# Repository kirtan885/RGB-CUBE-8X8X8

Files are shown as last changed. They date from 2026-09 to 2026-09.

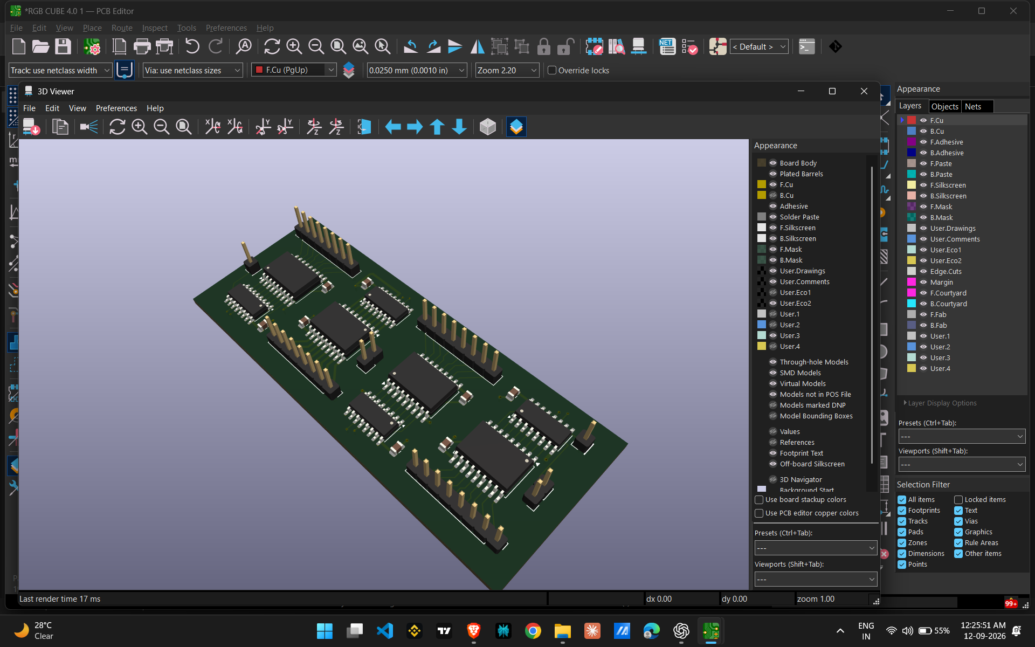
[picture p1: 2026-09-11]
images/Screenshot (306).png

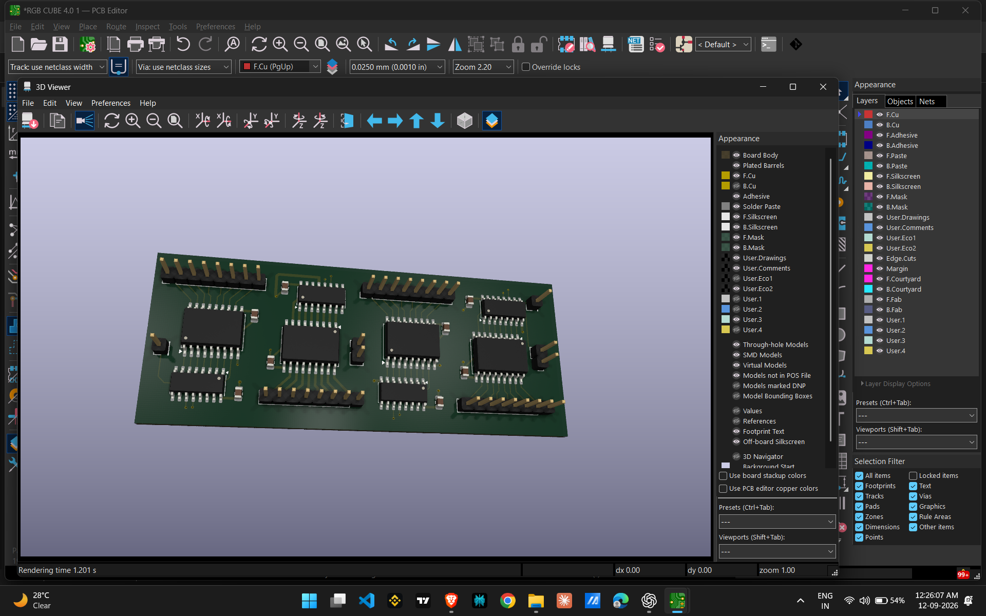
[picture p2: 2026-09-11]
images/pcb-3d.png

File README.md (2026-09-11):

# Arduino 74HC595 8-LED Driver Block Test

A Tinkercad/Arduino Uno validation project for an 8-channel LED driver block using a **74HC595 shift register** and **eight NPN transistor low-side switches**.

The purpose of this block is to validate one repeatable driver section before scaling the design into a larger multiplexed RGB LED cube system.

> **Project status:** Hardware-validation stage / prototype

## Overview

The tested block contains:

- 1 × Arduino Uno
- 1 × 74HC595 8-bit serial-to-parallel shift register
- 8 × NPN transistors (2N2222 / PN2222A or equivalent)
- 8 × LEDs
- 8 × 220 Ω LED current-limiting resistors
- 8 × 1 kΩ transistor base resistors
- 1 × 0.1 µF ceramic decoupling capacitor

The Arduino controls eight LED channels using only three digital control lines:

| Arduino | Signal | 74HC595 |
|---|---|---|
| D11 | Serial DATA | Pin 14, DS/SER |
| D13 | CLOCK | Pin 11, SHCP/SRCLK |
| D10 | LATCH | Pin 12, STCP/RCLK |

The 74HC595 converts the serial data stream into eight parallel outputs. Each output drives an NPN transistor through a 1 kΩ base resistor.

## Circuit architecture

```text
Arduino Uno
   │
   ├── D11 DATA ───────────────► 74HC595 Pin 14 (DS/SER)
   ├── D13 CLOCK ──────────────► 74HC595 Pin 11 (SHCP/SRCLK)
   └── D10 LATCH ──────────────► 74HC595 Pin 12 (STCP/RCLK)
                                  │
                 ┌────────────────┼────────────────┐
                 ▼                ▼                ▼
              Q0..Q7          8 outputs       Pin 9 Q7S
                 │
              1 kΩ each
                 │
                 ▼
            NPN transistor
                 │
        collector ──► LED + 220 Ω ──► +5 V
        emitter   ──────────────────► GND
```

### Low-side switching

For each channel, the intended current path is:

```text
+5V → LED anode → LED cathode → 220 Ω → NPN collector
NPN emitter → GND

74HC595 Q output → 1 kΩ → NPN base
```

When the 74HC595 output is HIGH, the NPN transistor turns on and completes the LED current path to ground.

**Important:** transistor lead order varies between manufacturers and packages. Verify the pin labels of the exact device before wiring a physical prototype.

## 74HC595 power/control wiring

| Arduino / Supply | 74HC595 pin | Function |
|---|---:|---|
| +5 V | 16 | VCC |
| GND | 8 | GND |
| D11 | 14 | DS / SER |
| D13 | 11 | SHCP / SRCLK |
| D10 | 12 | STCP / RCLK |
| GND | 13 | OE, active LOW |
| +5 V | 10 | SRCLR, active LOW |

Two control pins must not be left floating:

```text
74HC595 Pin 13 (OE)   → GND
74HC595 Pin 10 (SRCLR) → +5 V
```

A 0.1 µF ceramic capacitor should be placed close to the IC:

```text
74HC595 Pin 16 (VCC) ──||── 74HC595 Pin 8 (GND)
                       0.1 µF
```

## Output mapping

| Output | Physical pin | Connection |
|---|---:|---|
| Q0 | 15 | 1 kΩ → Transistor 1 base |
| Q1 | 1 | 1 kΩ → Transistor 2 base |
| Q2 | 2 | 1 kΩ → Transistor 3 base |
| Q3 | 3 | 1 kΩ → Transistor 4 base |
| Q4 | 4 | 1 kΩ → Transistor 5 base |
| Q5 | 5 | 1 kΩ → Transistor 6 base |
| Q6 | 6 | 1 kΩ → Transistor 7 base |
| Q7 | 7 | 1 kΩ → Transistor 8 base |
| Q7S / QH' | 9 | Not connected in the single-block test |

For future multi-register designs, Pin 9 (Q7S/QH') of one register connects to Pin 14 (DS/SER) of the next register.

## Bill of materials

| Qty | Component | Value / Type | Purpose |
|---:|---|---|---|
| 1 | Arduino Uno | 5 V board | Controller |
| 1 | 74HC595 | 8-bit shift register | Output expansion |
| 8 | NPN transistor | 2N2222 / PN2222A / equivalent | LED low-side switches |
| 8 | LED | Any color | Visual outputs |
| 8 | Resistor | 220 Ω | LED current limiting |
| 8 | Resistor | 1 kΩ | Transistor base current limiting |
| 1 | Capacitor | 0.1 µF / 104 ceramic | Decoupling |
| 1 | Breadboard | Full/half size | Prototype |
| Several | Jumper wires | — | Interconnects |

## Arduino test firmware

The test sketch runs five patterns:

1. All LEDs ON for approximately 1.5 s
2. All LEDs OFF for approximately 0.8 s
3. Running light from LED 1 to LED 8
4. Binary counter from 0 to 255
5. Bouncing light from one side to the other and back

The sketch uses `shiftOut()` to send eight serial bits and the latch line to update the parallel outputs.

See [`code/74hc595_8_led_test.ino`](code/74hc595_8_led_test.ino).

## Expected result

If all five patterns operate correctly, the following parts of the block have been exercised:

- Arduino-to-74HC595 serial communication
- DATA, CLOCK and LATCH connections
- 74HC595 power and control pins
- Q0–Q7 output mapping
- NPN transistor switching
- LED polarity
- LED current-limiting resistors
- transistor base resistors
- latch timing

## Troubleshooting

| Symptom | Likely cause | Check |
|---|---|---|
| No LEDs light | 74HC595 has no power | Pin 16 = +5 V, Pin 8 = GND |
| All LEDs remain off | OE floating/HIGH | Pin 13 → GND |
| LEDs behave unpredictably | SRCLR floating | Pin 10 → +5 V |
| Random/unstable behavior | Missing decoupling | Add 0.1 µF close to the IC |
| Only some LEDs work | Q-pin mapping error | Q0 = pin 15; Q1–Q7 = pins 1–7 |
| LED stays on | Transistor/LED wiring issue | Check base, collector, emitter and polarity |
| LED does not light | LED reversed | Anode toward +5 V; cathode toward resistor/transistor |
| Sequence is wrong | Physical LED order differs | Match LED order to Q0–Q7 |

## Scaling toward the LED cube

The validated block is intended as the foundation for a larger LED-cube driver.

```text
1 × 74HC595  → 8 output channels
2 × 74HC595  → 16 output channels
8 × 74HC595  → 64 output channels
24 × 74HC595 → 192 output channels
```

For chained registers:

```text
Arduino D11
   │
   ▼
74HC595 #1 DS
   │
   └── Q7S ──► 74HC595 #2 DS
                  │
                  └── Q7S ──► 74HC595 #3 DS
                                  ...
```

Clock and latch are shared:

```text
Arduino D13 → SHCP/SRCLK on every 74HC595
Arduino D10 → STCP/RCLK on every 74HC595
Arduino D11 → DS/SER on the first 74HC595
```

The larger multiplexed cube concept uses shift-register output channels for LED cathode/color control plus separate layer/plane drivers.

## Relationship to the 8×8×8 RGB LED Cube

The broader project explores two possible architectures:

### Traditional multiplexed RGB cube

The earlier design concept uses common-anode 5 mm RGB LEDs, chained shift registers, transistor/Darlington current sinks, and separate layer switching.

A PCB screenshot in the project history shows a larger multi-register driver layout and its 3D view. That design should be treated as a **separate scaling stage**, not as part of this validated single 74HC595 block.

### Addressable LED cube

A separate project direction considered WS2812B/SK6812/WS2813-style addressable LEDs to reduce driver and wiring complexity.

This repository documents the **74HC595 block validation**. The addressable architecture is therefore kept as a future/alternative direction rather than mixed into the tested circuit.

## Suggested repository structure

```text
arduino-74hc595-8-led-driver/
├── README.md
├── LICENSE
├── code/
│   └── 74hc595_8_led_test.ino
├── circuit/
│   ├── tinkercad-circuit-link.txt
│   ├── wiring-diagram.png
│   └── schematic.png
├── docs/
│   ├── connection-table.md
│   ├── troubleshooting.md
│   ├── assembly-testing-guide.md
│   └── future-led-cube-plan.md
└── images/
    ├── tinkercad-overview.png
    ├── pcb-2d.png
    └── pcb-3d.png
```

## Key learning outcomes

- Expand Arduino outputs using a 74HC595.
- Use `shiftOut()` for serial-to-parallel control.
- Use a latch signal to update multiple outputs together.
- Drive LEDs through NPN low-side switches.
- Use a 1 kΩ resistor for transistor base current limiting.
- Use a 220 Ω resistor for LED current limiting.
- Tie OE to GND and SRCLR to +5 V for stable operation.
- Add local 0.1 µF decoupling.
- Validate one repeatable block before scaling to a larger PCB/cube.

## License

Choose a license appropriate for your hardware and software. MIT is a simple option for the firmware and documentation if you want to permit reuse.

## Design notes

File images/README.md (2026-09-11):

# Project Images

- `pcb-2d.png` — supplied KiCad PCB Editor view.
- `pcb-3d.png` — supplied KiCad 3D Viewer view.

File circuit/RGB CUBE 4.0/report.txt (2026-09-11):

Front (top side) placement file: 'E:\learn pcb degine\RGB CUBE 4.0\COM PLACM\RGB CUBE 4.0 1-top.pos'.
Info: Component count: 16.
Back (bottom side) placement file: 'E:\learn pcb degine\RGB CUBE 4.0\COM PLACM\RGB CUBE 4.0 1-bottom.pos'.
Info: Component count: 0.
Info: Full component count: 16.
Info: Done.
Front (top side) placement file: 'E:\learn pcb degine\RGB CUBE 4.0\COM PLACM\RGB CUBE 4.0 1-top.pos'.
Info: Component count: 16.
Back (bottom side) placement file: 'E:\learn pcb degine\RGB CUBE 4.0\COM PLACM\RGB CUBE 4.0 1-bottom.pos'.
Info: Component count: 0.
Info: Full component count: 16.
Info: Done.
Front (top side) placement file: 'E:\learn pcb degine\RGB CUBE 4.0\COM PLACM\RGB CUBE 4.0 1-top.pos'.
Info: Component count: 16.
Back (bottom side) placement file: 'E:\learn pcb degine\RGB CUBE 4.0\COM PLACM\RGB CUBE 4.0 1-bottom.pos'.
Info: Component count: 0.
Info: Full component count: 16.
Info: Done.

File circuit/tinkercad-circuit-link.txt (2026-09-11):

Paste the public Tinkercad Circuits URL here.

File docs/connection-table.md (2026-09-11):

# Connection Table

## Arduino → 74HC595

| Arduino | 74HC595 pin | Signal |
|---|---:|---|
| 5 V | 16 | VCC |
| GND | 8 | GND |
| D11 | 14 | DS / SER |
| D13 | 11 | SHCP / SRCLK |
| D10 | 12 | STCP / RCLK |
| GND | 13 | OE |
| 5 V | 10 | SRCLR |

## 74HC595 outputs

| Output | Pin | Destination |
|---|---:|---|
| Q0 | 15 | 1 kΩ → NPN 1 base |
| Q1 | 1 | 1 kΩ → NPN 2 base |
| Q2 | 2 | 1 kΩ → NPN 3 base |
| Q3 | 3 | 1 kΩ → NPN 4 base |
| Q4 | 4 | 1 kΩ → NPN 5 base |
| Q5 | 5 | 1 kΩ → NPN 6 base |
| Q6 | 6 | 1 kΩ → NPN 7 base |
| Q7 | 7 | 1 kΩ → NPN 8 base |

Pin 9 (Q7S/QH') is unused in this single-register test.

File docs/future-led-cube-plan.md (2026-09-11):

# Future LED Cube Plan

The single 74HC595 block is intended as a hardware-validation step for a larger LED-cube project.

## Shift-register scaling

```text
1 × 74HC595  → 8 channels
2 × 74HC595  → 16 channels
8 × 74HC595  → 64 channels
24 × 74HC595 → 192 channels
```

Registers are chained through Q7S/QH':

```text
First 74HC595 Q7S → Next 74HC595 DS
Next Q7S           → Next DS
```

The DATA line enters only the first register. CLOCK and LATCH are shared.

## Traditional multiplexed RGB cube direction

The broader design concept uses:

- Common-anode RGB LEDs
- Multiple 74HC595 shift registers
- Low-side current-sink/transistor stages
- Separate high-side layer switching
- Arduino Uno / UNO R4 WiFi / ESP32 as possible controllers

The exact final PCB architecture should be treated as a separate design stage after the driver block has been validated.

## Alternative addressable direction

Another explored architecture uses WS2812B/SK6812/WS2813-style addressable LEDs.

That approach is significantly different electrically and should not be mixed with the 74HC595 driver-block design without a new schematic and power analysis.

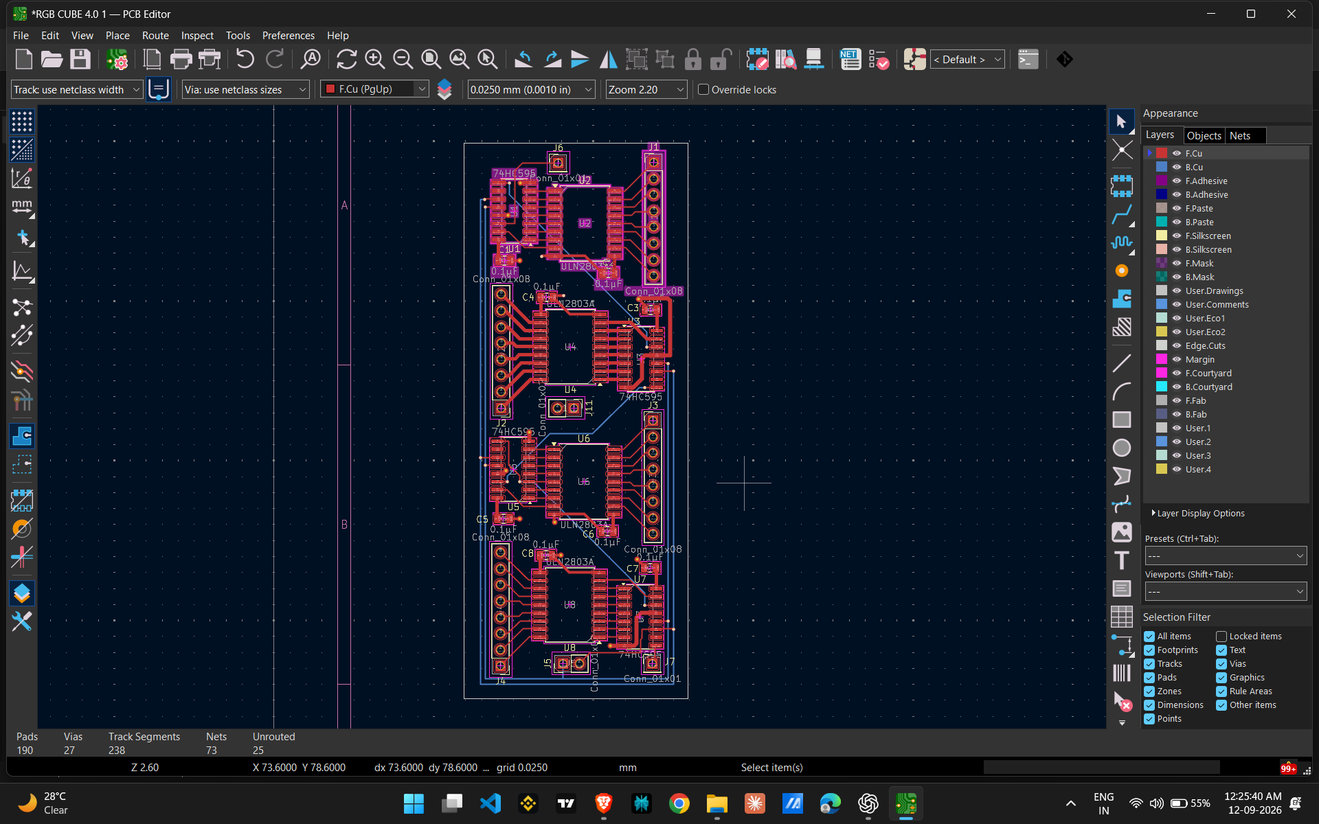
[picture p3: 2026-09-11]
images/pcb-2d.png

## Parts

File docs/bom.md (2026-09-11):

# Bill of Materials — 74HC595 8-LED Driver Block

| Qty | Component | Value / Type | Purpose |
|---:|---|---|---|
| 1 | Arduino Uno | 5 V microcontroller board | Controller |
| 1 | 74HC595 | 8-bit shift register | Output expansion |
| 8 | NPN transistor | 2N2222 / PN2222A / equivalent | Low-side LED switching |
| 8 | LED | Any color | Visual output |
| 8 | Resistor | 220 Ω | LED current limiting |
| 8 | Resistor | 1 kΩ | Transistor base current limiting |
| 1 | Capacitor | 0.1 µF / 104 ceramic | Decoupling |
| 1 | Breadboard | Full or half size | Prototype |
| Several | Jumper wires | — | Connections |

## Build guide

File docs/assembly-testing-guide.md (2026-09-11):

# Assembly & Testing Guide

## 1. Build the power section

Connect:

- Arduino +5 V to 74HC595 pin 16.
- Arduino GND to 74HC595 pin 8.
- 0.1 µF ceramic capacitor close to the 74HC595 between VCC and GND.

## 2. Configure the control pins

Connect:

- Arduino D11 → 74HC595 pin 14 (DATA).
- Arduino D13 → 74HC595 pin 11 (CLOCK).
- Arduino D10 → 74HC595 pin 12 (LATCH).
- 74HC595 pin 13 (OE) → GND.
- 74HC595 pin 10 (SRCLR) → +5 V.

## 3. Build one LED channel first

Before building all eight channels, test one:

```text
+5V → LED anode
LED cathode → 220 Ω
220 Ω → NPN collector
NPN emitter → GND
74HC595 Q0 → 1 kΩ → NPN base
```

Confirm that the transistor package pinout matches the device you are using.

## 4. Duplicate the channel

Repeat the same arrangement for Q1 through Q7.

## 5. Upload the firmware

Open:

`code/74hc595_8_led_test.ino`

Select the correct Arduino Uno board and serial port, then upload.

## 6. Observe the five tests

Expected sequence:

1. All LEDs ON.
2. All LEDs OFF.
3. Running light.
4. Binary counter.
5. Bouncing light.

## 7. Debug systematically

If the first channel fails, do not build the remaining seven. Verify power, OE, SRCLR, LED polarity, transistor pinout and the Q0 connection first.

Once Q0 works, duplicate the proven channel and verify Q1–Q7.

## 8. Before scaling

Only proceed to a larger PCB after the single block is stable in both simulation and physical prototype testing.

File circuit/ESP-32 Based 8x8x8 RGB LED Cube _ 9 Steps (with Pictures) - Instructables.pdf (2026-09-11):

## ESP-32 Based 8x8x8 RGB LED Cube

By JohnLukito (https://www.instructables.com/member/JohnLukito/) in Circuits (https://www.instructables.com/circuits/projects) | LEDs (https://www.instructables.com/circuits/leds/projects) | 5,621 | 33 | Featured

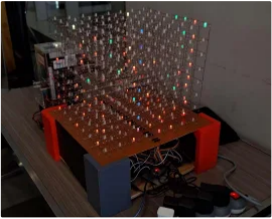
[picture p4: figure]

Hi Everyone! My name is John Lukito (2540124223) , and I'm a second-year student at Binus University studying Computer Engineering. I am thrilled to be working on this project alongside my talented peers, Michael Angelo Chandra (2540131481) and Johevin Blesstowi (2502036262) , who are also pursuing the same major. Together, we aim to delve into the fascinating world of the RGB LED cube and explore how cloud connectivity can enhance the functionality of this captivating device.

An 8x8x8 RGB LED cube is a visually captivating electronic device. It consists of 512 individually addressable RGB LEDs arranged as an 8x8x8 cube. Each LED can independently emit red, green, and blue colors, allowing for a wide range of vibrant color combinations and dynamic lighting effects. By controlling the brightness and color of each LED, intricate patterns, animations, and even 3D images can be created.

In our project, we aim to integrate cloud connectivity into the 8x8x8 RGB LED cube to explore the benefits it can bring. By connecting the LED cube to the cloud, we can leverage the power of the internet and remote devices to trivialize the animation selection process. This connectivity will enable us to access a vast library of pre-defined animations or even create our own custom animations using cloud-based tools (on-progress). Additionally, cloud connectivity can provide real-time synchronization, allowing the LED cube to display animations on-demand, creating a responsive and easy-to-use experience.

With the combination of the 8x8x8 RGB LED cube and cloud connectivity via Firebase, we aim to push the boundaries of creativity and interactivity in lighting displays. By harnessing the power of the cloud, we can tap into a virtually limitless array of animations and dynamically control the cube's visual output. Stay tuned as we embark on this exciting project step-by-step and build one for ourselves.

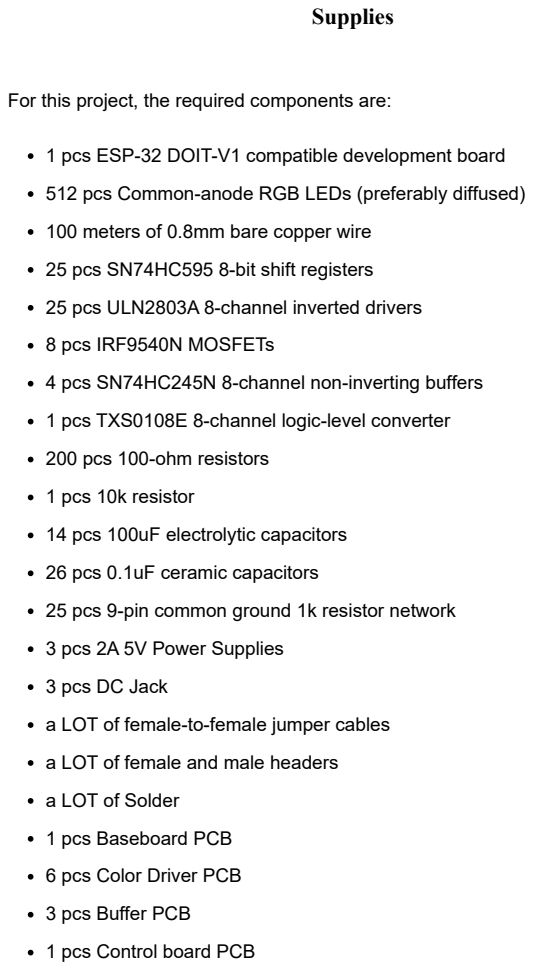
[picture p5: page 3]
Supplies

For this project, the required components are:

1 pcs ESP-32 DOIT-V1 compatible development board
512 pcs Common-anode RGB LEDs (preferably diffused)
100 meters of 0.8mm bare copper wire
25 pcs SN74HC595 8-bit shift registers
25 pcs ULN2803A 8-channel inverted drivers
8 pcs IRF9540N MOSFETs
4 pcs SN74HC245N 8-channel non-inverting buffers
1 pcs TXS0108E 8-channel logic-level converter
200 pcs 100-ohm resistors
1 pcs 10k resistor
14 pcs 100uF electrolytic capacitors
26 pcs 0.1uF ceramic capacitors
25 pcs 9-pin common ground 1k resistor network
3 pcs 2A 5V Power Supplies
3 pcs DC Jack
a LOT of female-to-female jumper cables
a LOT of female and male headers
a LOT of Solder
1 pcs Baseboard PCB
6 pcs Color Driver PCB
3 pcs Buffer PCB
1 pcs Control board PCB

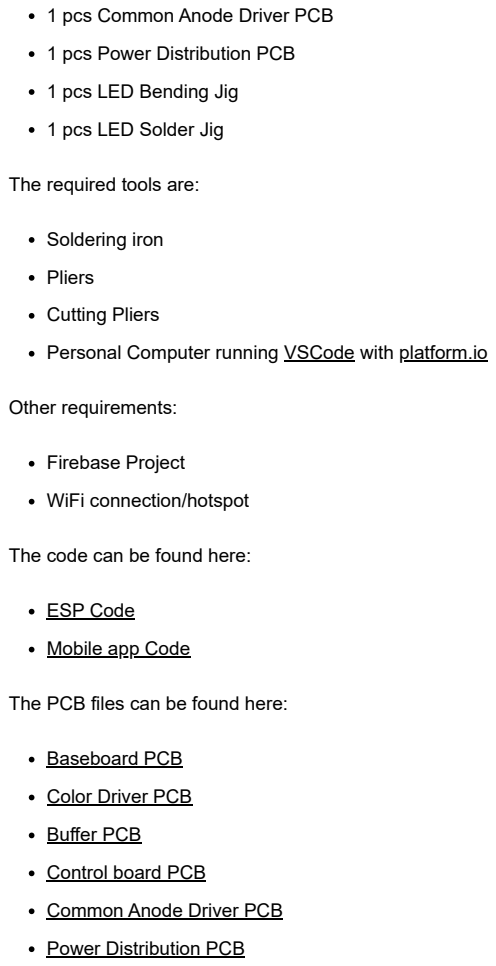
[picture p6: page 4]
Other requirements:

1 pcs Common Anode Driver PCB
1 pcs Power Distribution PCB
1 pcs LED Bending Jig
1 pcs LED Solder Jig

The required tools are:

Soldering iron
Pliers
Cutting Pliers
Personal Computer running VSCode (https://code.visualstudio.com/download) with platform.io (https://platformio.org/install/ide?install=vscode)

Firebase Project
WiFi connection/hotspot

The code can be found here:

ESP Code (https://github.com/JohnLkt/8x8x8-LED-Cube)
Mobile app Code (https://github.com/michaelAngelo1/ledcubeapp/tree/staging)

The PCB files can be found here:

Baseboard PCB (https://oshwlab.com/john.lukito/8-8-8-rgb-led-cube-base-board)
Color Driver PCB (https://oshwlab.com/john.lukito/rgb-led-color-driver)
Buffer PCB (https://oshwlab.com/john.lukito/signal-buffer-daughter-boards)
Control board PCB (https://oshwlab.com/john.lukito/8-8-8-rgb-led-cube-control-board)
Common Anode Driver PCB (https://oshwlab.com/john.lukito/rgb-led-common-anode-driver)
Power Distribution PCB (https://oshwlab.com/john.lukito/rgb-led-power-distribution-board)

*note that the PCBs are designed to be hand-etched on single-layer boards as many of the connections require manual jumpers*

The Jig files can be found below in the attachments of this section.

### Step 1: Test All the LEDs

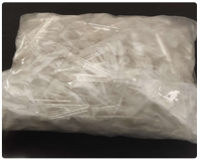
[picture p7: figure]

The first thing to do after your LEDs arrive is to test all 512 RGB LEDs and make sure all of them work properly. This step is VERY IMPORTANT as it will save you many hours of headaches later on.

To test the LEDs, it is recommended to set up a testing jig using this schematic:

The positive wire of the power supply is in series with a 200-ohm resistor, then connected to the common anode lead of the RGB LED (the longest one). Then, using a jumper cable connected to the negative side of the power supply, you can touch the R, G, and B leads and confirm that each color lights up properly.

If at any point a color fails to light up, discard the LED to a separate container. You do not want good LEDs to be mixed up with defective ones.

### Step 2: Bend All the LEDs

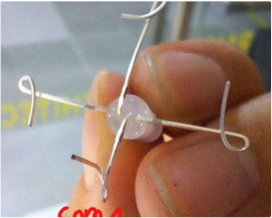
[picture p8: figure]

Use the Bending Jig to bend the LEDs such as shown above. Note that the common anode lead must also be bent sideways so that it is perpendicular to the other leads.

Do this for all 512 LEDs. make sure to do them consistently as mistakes here can cause major headaches at a later step.

### Step 3: Measure, Cut, and Straighten Cables

measure and cut 40cm lengths of cable, then straighten them out using a hand drill on one end and a plier at the other end.

After you have done this for the amount of wire needed, you can proceed to the next step

*note if you plan on storing the wires for over 3 days, you might need to sand the wires before soldering them to the LED layers since bare copper wire oxidize quickly*

### Step 4: Solder the LED Layers Using the Jig

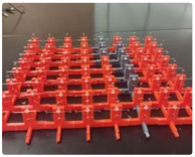
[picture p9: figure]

The first thing to do in this step is to put 64 LEDs (for a single layer) into the soldering Jig in a consistent manner (Common Anode side down) such as in the picture below:

after all the LEDs are in place, next is putting the straightened copper wire through the bends in the R, G and B leads. For this step some twisting and untightening the bends might be required to get the wire all the way through such as in the picture below:

Next is soldering the leads to the wire, be patient and generous, don't be scared to use too much solder as you can always remove it later. Not enough solder or bad soldering can cause brittle joints which will cause problems later on.

After the color leads are soldered, we solder the common anode leads the same way, then we pop-out the LED plane from the Jig and store it until we have completed all 8 LED planes.

After completion of this step, it is also wise to test the solder connections using a multimeter or by using the same testing Jig as used to test the individual LEDs, but this time 5V is wired to the horizontal wires (common anode) and the negative side is touched to the R, G, or B wires.

### Step 5: Prepare the Baseboard PCB

For this step, we must prepare the elongated male headers to be soldered to the pads at the bottom side of the PCB. this is done by first cutting the male headers into 1x8 configuration, then using a hard and flat surface, push down evenly using your pliers for additional stability so that the plastic piece slides to the end of the metal pins like in the picture below:

Then solder the headers to the baseboard PCB according to the schematic given.

### Step 6: Cube Assembly

After the male headers have been soldered to the Baseboard PCB properly, the next step is to assemble the cube by soldering the LED planes to the corresponding holes. This is done by first aligning each plane and putting the spare wire at the bottom through the holes, then using part of the soldering jig to hold space between the planes, to solder the wires from the bottom of the baseboard.

after soldering and making sure the connections are good, cut off the excess wire using your cutting pliers.

Next is to wire the levels together, use the same straightened bare copper to connect the planes horizontally, then use more wire to connect each horizontal plane to each of the holes at the side of the PCB sequentially.

### Step 7: Prepare the Other PCBs

After the cube itself is assembled, we must complete all the control circuitry. First things first is to solder all the components into the board (remember to not solder ICs directly into the board, use IC sockets instead. The same applies for the development modules, please use female headers to interface with the PCB for ease of use). During this process make sure to get each placed correctly with the right orientation as well. For this refer to the PCB schematic given above.

Next is to solder the manual jumper cables, this is done by taking insulated copper wire (such as the ones used for the female-female jumpers, and wiring them up according to the top layer traces as shown in the PCB schematic given above.

After the board is finished, test them using a multimeter to make sure the connections are according to plan and that no shorts have taken place.

### Step 8: Circuit Assembly

First is to plug all the integrated components to the PCBs such as the ICs and the ESP-32 in their respective places (please refer to the PCB Schematic given above).

Next is to wire up the power distribution board to all the other boards grouped like this: all the buffer PCBs and the main controller PCB is wired up to the first DC jack, all the color driver boards are wired to the second DC jack, and the common anode driver board is wired to the third DC jack.

Next is to wire up the signal cables between the PCBs, make sure the connections are solid so that no signal dropouts will happen.

Last is to connect the signal out headers to the LED cube Baseboard PCB.

### Step 9: Setup and Upload Code

First step is to download Visual Studio Code and PlatformIO from the links given above if you haven't already.

Next is downloading the code or cloning the repository from Github.

After the code environment is established. we must add a file inside the "src" folder called "credentials.h"

inside it we shall define the following:

#define WIFI_SSID ""

#define WIFI_PASSWORD ""

// wifi network credentials

#define API_KEY ""

#define DATABASE_URL ""

#define FIREBASE_PROJECT_ID ""

//firebase project credentials

#define USER_EMAIL ""

#define USER_PASSWORD ""

//firebase auth user credentials

After the file has been created and filled with sufficient credentials, you can compile and upload the code to the ESP-32

After which, controlling the on/off state of the LED cube or which animation it will play is a matter of changing values inside the Firebase RTDB console or via the mobile application.

Enjoy :D

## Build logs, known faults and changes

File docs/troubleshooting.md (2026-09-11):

# Troubleshooting

| Symptom | Likely cause | Fix |
|---|---|---|
| No LEDs light | 74HC595 power missing | Pin 16 → +5 V, Pin 8 → GND |
| All LEDs off | OE disabled | Pin 13 → GND |
| Unstable/random outputs | SRCLR floating | Pin 10 → +5 V |
| Unstable switching | No decoupling | Place 0.1 µF close to VCC/GND |
| Only some channels work | Wrong Q-pin mapping | Verify Q0 pin 15 and Q1–Q7 pins 1–7 |
| LED stays on | Transistor wiring error | Verify base, collector and emitter |
| LED does not light | LED polarity reversed | Anode toward +5 V |
| Wrong sequence | Physical channel order differs | Match LED order to Q0–Q7 |

For physical 2N2222/PN2222A devices, verify the package pinout from the specific manufacturer's datasheet. Do not assume every transistor has the same lead order.

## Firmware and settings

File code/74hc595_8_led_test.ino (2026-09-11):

// =============================================
// 74HC595 + PN2222A Transistor Test
// Arduino Uno - Single Block with 8 LEDs
//
// D10 = LATCH
// D11 = DATA
// D13 = CLOCK
// =============================================

const int LATCH = 10;
const int DATA  = 11;
const int CLK   = 13;

void setup() {
  pinMode(LATCH, OUTPUT);
  pinMode(DATA, OUTPUT);
  pinMode(CLK, OUTPUT);

  sendByte(0b00000000);  // Start with all LEDs OFF
}

void sendByte(byte value) {
  digitalWrite(LATCH, LOW);

  shiftOut(DATA, CLK, MSBFIRST, value);

  digitalWrite(LATCH, HIGH);
  delayMicroseconds(10);
  digitalWrite(LATCH, LOW);
}

void loop() {

  // Test 1: Turn all LEDs ON
  sendByte(0b11111111);
  delay(1500);

  // Test 2: Turn all LEDs OFF
  sendByte(0b00000000);
  delay(800);

  // Test 3: Running-light test
  for (int i = 0; i < 8; i++) {
    sendByte(1 << i);
    delay(150);
  }

  sendByte(0);
  delay(400);

  // Test 4: Binary counter, 0 to 255
  for (int value = 0; value < 256; value++) {
    sendByte((byte)value);
    delay(80);
  }

  delay(500);

  // Test 5: Bouncing LED
  for (int i = 0; i < 7; i++) {
    sendByte(1 << i);
    delay(100);
  }

  for (int i = 7; i >= 0; i--) {
    sendByte(1 << i);
    delay(100);
  }

  sendByte(0);
  delay(400);
}
